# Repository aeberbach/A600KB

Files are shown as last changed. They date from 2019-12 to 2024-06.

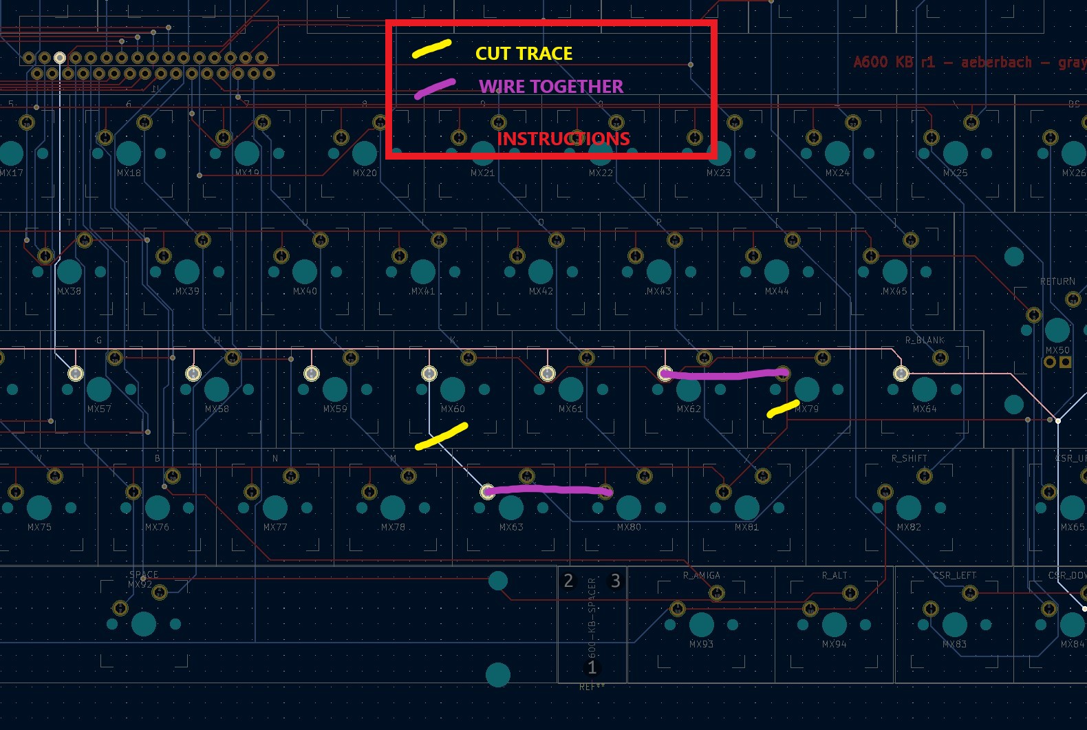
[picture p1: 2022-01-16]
A600-kb-fix.jpg

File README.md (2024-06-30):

# A600KB: Mechanical keyboard Amiga A600

Like my A1200 project (see my other repos) this is a mechanical keyboard for an Amiga computer.

To make one you need:
- PCBs, which you can make by sending the contents of the 'fab' folder to your local PCB maker.
- 3D printed parts: the STL files are in the STL folder. I used a Prusa MK3S 0.25mm nozzle, Urban Grey PETG.
- 78 MX PCB-mount switches
- 32-way FFC connector (Mouser part number 538-52044-3245)
- 32-way ribbon cable (Mouser part number 538-15168-0400)
- keyswitch stabiliser for Tab and Enter keys
- one 3mm LED for CapsLock
- keycaps

For more details about design choices and putting it together please see the article on grayunicorn.com. 

Enjoy!

May 2022 Update - this is now release 2. Apart from correcting swapped keys that existed in revision 1 (see below) I made a lot of traces simpler. I used KiCAD 6 for this, it just keeps getting better. If you build a revision 2 I would love to hear about it.

Revision 1 Errata:
Many people have built it and never noticed. That goes for me too - one person contacted me and said they were having trouble with some music tracker software because it relies on the keys that are not in the right place. I had not noticed because I had not been using software that relied on those
keys - sorry if you were affected! The revision 1 PCB should be modified:

- Line 5: disconnect from MX63 (< ,) column; connect to MX79 (" ') column
- Line 7: disconnect from MX79 (" ') column; connect to MX63 (< ,) column
- Line 23: disconnect from MX79 (" ') row; connect to MX63 (< ,) row
- Line 26: disconnect from MX63 (< ,) row; connect to MX79 (" ') row

The PCB has been revised to revision 2 (the same as Commodore's schematic) now so this is fixed, but if you have a revision 1 and notice the ' and , appear to be swapped then you may need to apply this change.

Note this this project is licensed under CC BY-NC-SA 4.0 - only noncommercial use is permitted! (By all means sell the excess PCBs you get, at cost, if you order some for your own use)

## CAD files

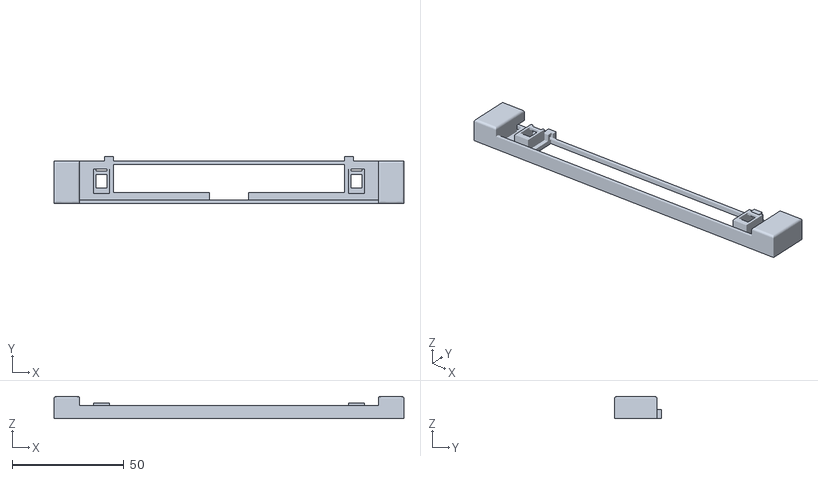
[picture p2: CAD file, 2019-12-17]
STL/A600-7U-Spacebar-Assembly.stl
156.5 x 21.0 x 10.0

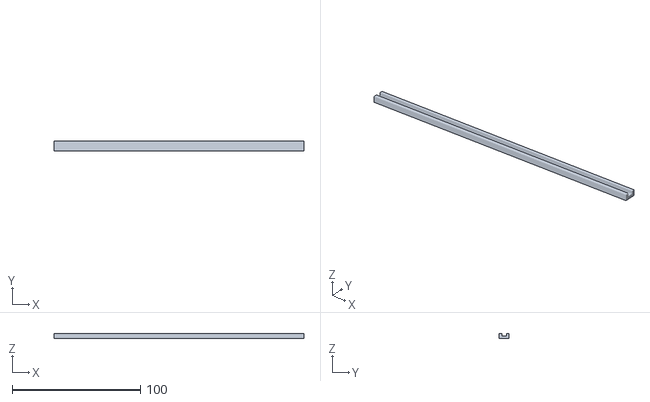
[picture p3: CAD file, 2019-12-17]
STL/Rail.stl
195.0 x 8.00 x 4.00

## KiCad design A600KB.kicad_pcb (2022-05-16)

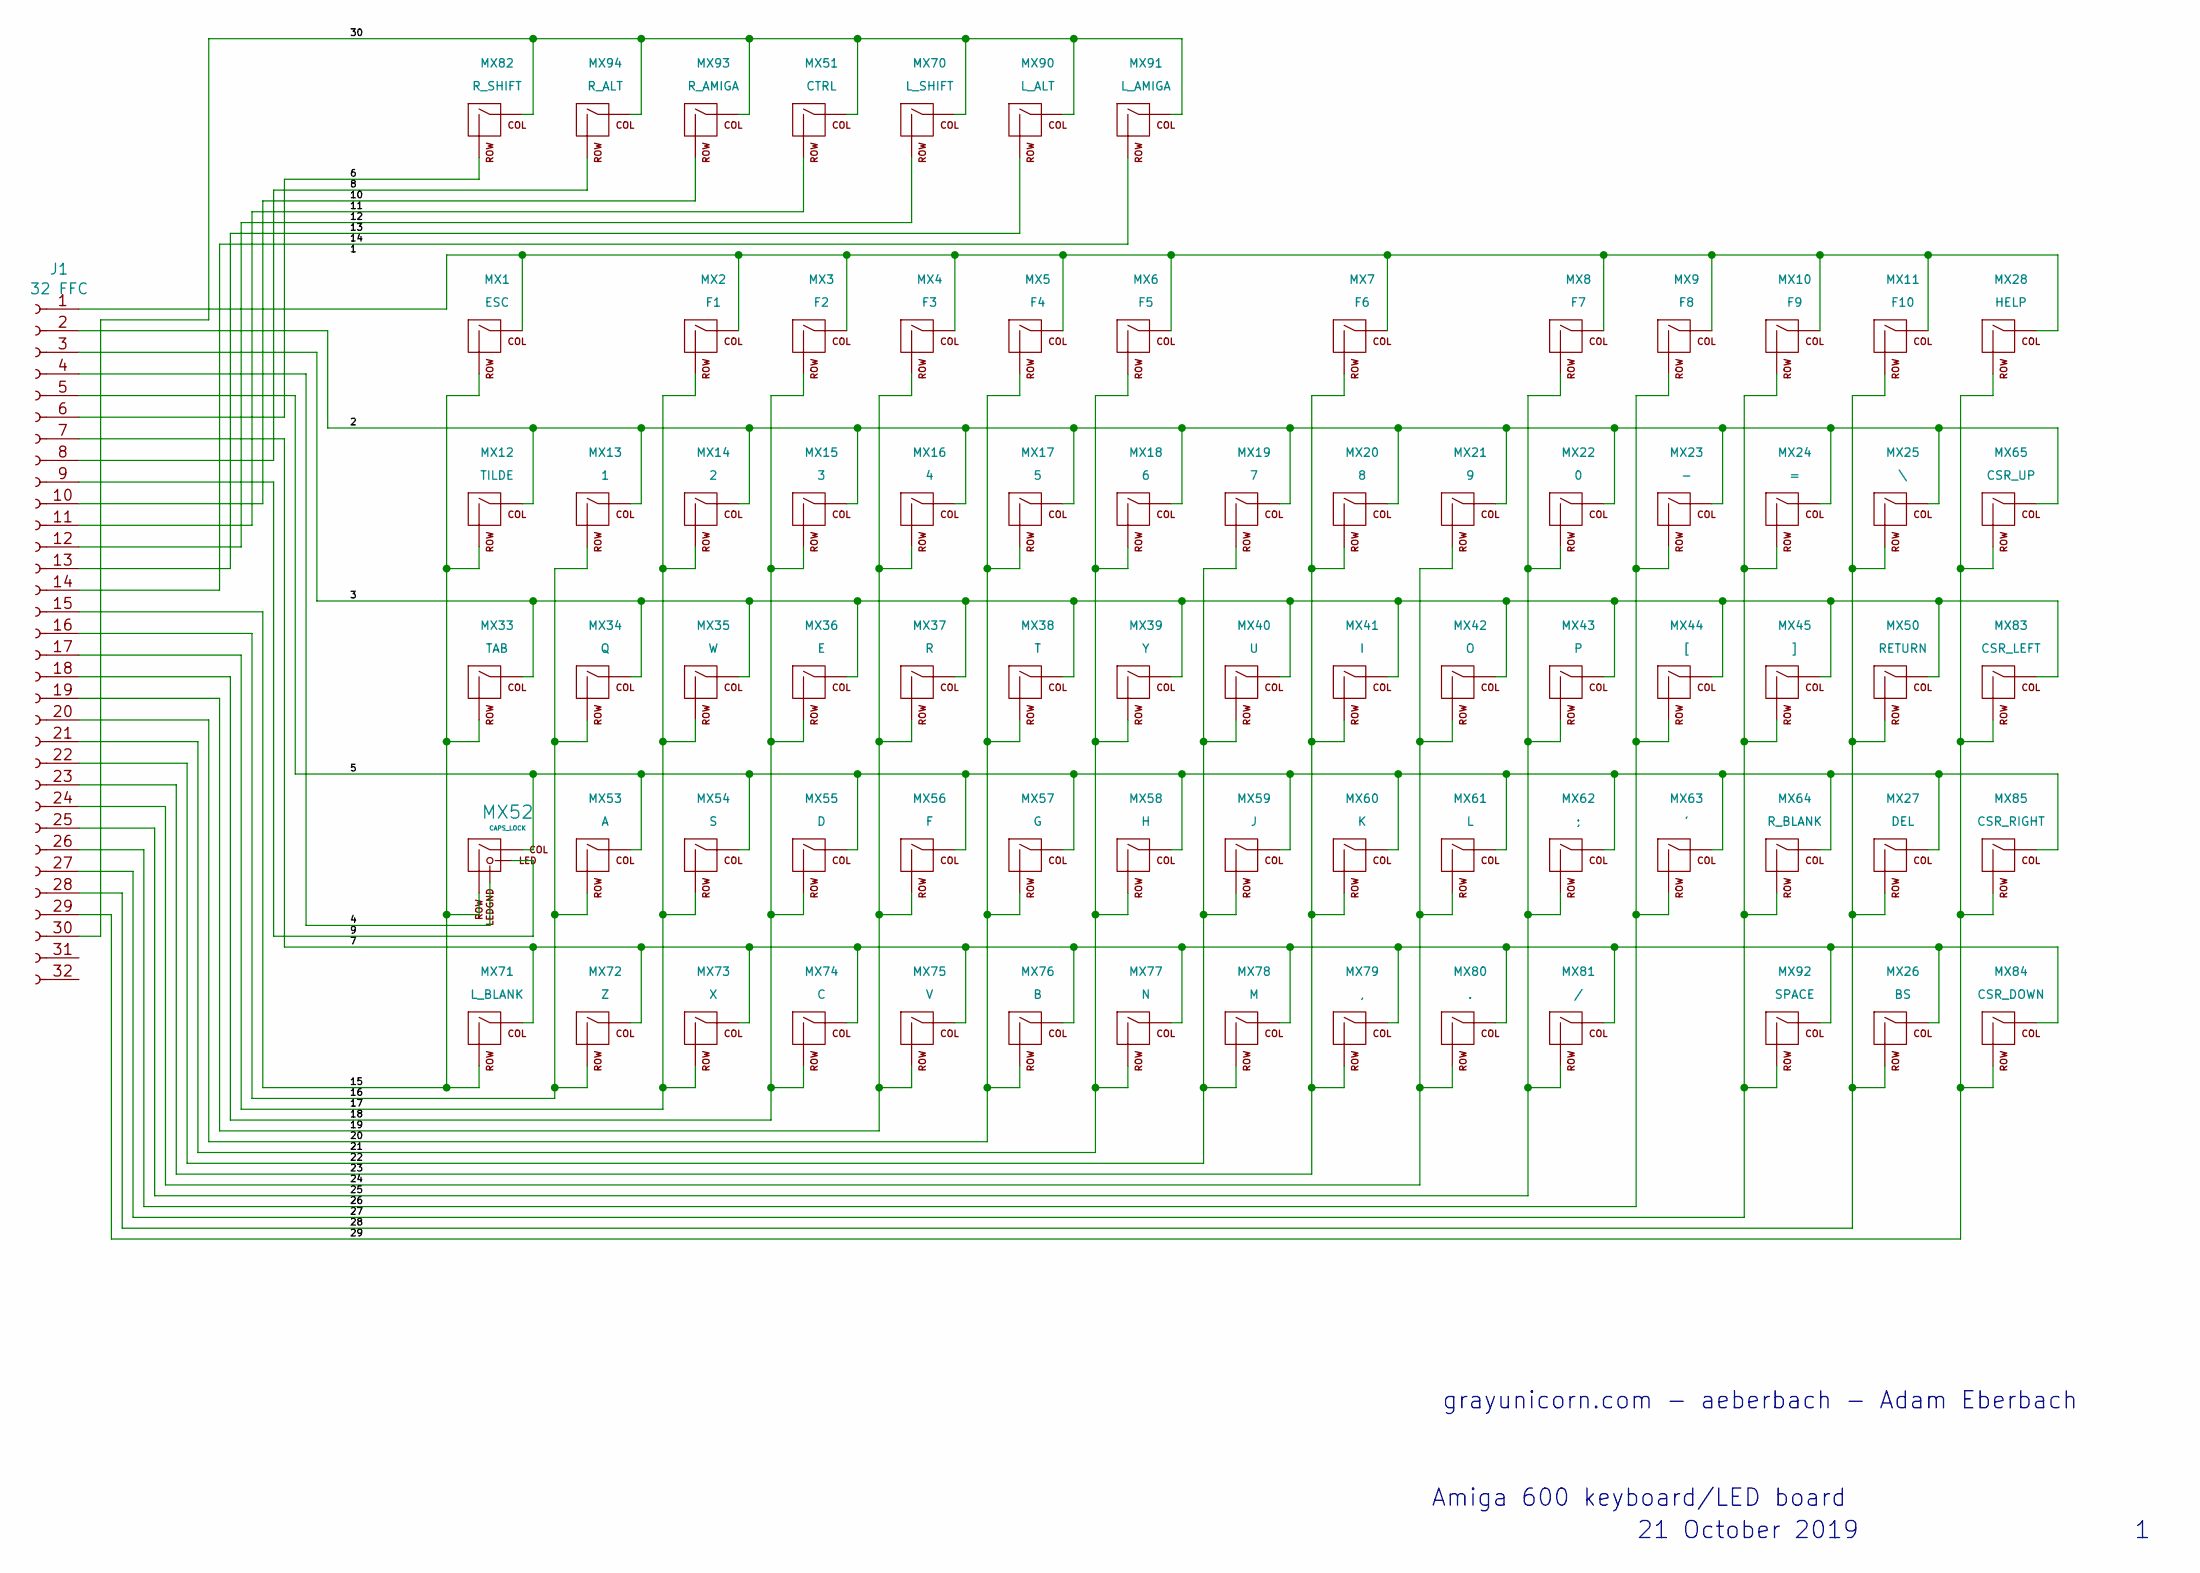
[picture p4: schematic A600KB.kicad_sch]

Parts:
J1: 32 FFC; FFC-1.25mm-RA-5204403245
MX1: ESC; MXOnly-1.25U-NoLED
MX2: F1; MXOnly-1.25U-NoLED
MX3: F2; MXOnly-1.25U-NoLED
MX4: F3; MXOnly-1.25U-NoLED
MX5: F4; MXOnly-1.25U-NoLED
MX6: F5; MXOnly-1.25U-NoLED
MX7: F6; MXOnly-1.25U-NoLED
MX8: F7; MXOnly-1.25U-NoLED
MX9: F8; MXOnly-1.25U-NoLED
MX10: F9; MXOnly-1.25U-NoLED
MX11: F10; MXOnly-1.25U-NoLED
MX12: TILDE; MXOnly-1.5U-NoLED
MX13: 1; MXOnly-1U-NoLED
MX14: 2; MXOnly-1U-NoLED
MX15: 3; MXOnly-1U-NoLED
MX16: 4; MXOnly-1U-NoLED
MX17: 5; MXOnly-1U-NoLED
MX18: 6; MXOnly-1U-NoLED
MX19: 7; MXOnly-1U-NoLED
MX20: 8; MXOnly-1U-NoLED
MX21: 9; MXOnly-1U-NoLED
MX22: 0; MXOnly-1U-NoLED
MX23: -; MXOnly-1U-NoLED
MX24: =; MXOnly-1U-NoLED
MX25: \; MXOnly-1U-NoLED
MX26: BS; MXOnly-1U-NoLED
MX27: DEL; MXOnly-1U-NoLED
MX28: HELP; MXOnly-1.25U-NoLED
MX33: TAB; MXOnly-2U-NoLED
MX34: Q; MXOnly-1U-NoLED
MX35: W; MXOnly-1U-NoLED
MX36: E; MXOnly-1U-NoLED
MX37: R; MXOnly-1U-NoLED
MX38: T; MXOnly-1U-NoLED
MX39: Y; MXOnly-1U-NoLED
MX40: U; MXOnly-1U-NoLED
MX41: I; MXOnly-1U-NoLED
MX42: O; MXOnly-1U-NoLED
MX43: P; MXOnly-1U-NoLED
MX44: [; MXOnly-1U-NoLED
MX45: ]; MXOnly-1U-NoLED
MX50: RETURN; MXOnly-ISO
MX51: CTRL; MXOnly-1.25U-NoLED
MX52: CAPS_LOCK; MXOnly-1U
MX53: A; MXOnly-1U-NoLED
MX54: S; MXOnly-1U-NoLED
MX55: D; MXOnly-1U-NoLED
MX56: F; MXOnly-1U-NoLED
MX57: G; MXOnly-1U-NoLED
MX58: H; MXOnly-1U-NoLED
MX59: J; MXOnly-1U-NoLED
MX60: K; MXOnly-1U-NoLED
MX61: L; MXOnly-1U-NoLED
MX62: ;; MXOnly-1U-NoLED
MX63: '; MXOnly-1U-NoLED
MX64: R_BLANK; MXOnly-1U-NoLED
MX65: CSR_UP; MXOnly-1U-NoLED
MX70: L_SHIFT; MXOnly-1.75U-NoLED
MX71: L_BLANK; MXOnly-1U-NoLED
MX72: Z; MXOnly-1U-NoLED
MX73: X; MXOnly-1U-NoLED
MX74: C; MXOnly-1U-NoLED
MX75: V; MXOnly-1U-NoLED
MX76: B; MXOnly-1U-NoLED
MX77: N; MXOnly-1U-NoLED
MX78: M; MXOnly-1U-NoLED
MX79: ,; MXOnly-1U-NoLED
MX80: .; MXOnly-1U-NoLED
MX81: /; MXOnly-1U-NoLED
MX82: R_SHIFT; MXOnly-1.75U-NoLED
MX83: CSR_LEFT; MXOnly-1U-NoLED
MX84: CSR_DOWN; MXOnly-1U-NoLED
MX85: CSR_RIGHT; MXOnly-1U-NoLED
MX90: L_ALT; MXOnly-1.25U-NoLED
MX91: L_AMIGA; MXOnly-1.25U-NoLED
MX92: SPACE; MXOnly-7U
MX93: R_AMIGA; MXOnly-1.25U-NoLED
MX94: R_ALT; MXOnly-1U-NoLED

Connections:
/2: J1.2, MX12.1 (COL), MX13.1 (COL), MX14.1 (COL), MX15.1 (COL), MX16.1 (COL), MX17.1 (COL), MX18.1 (COL), MX19.1 (COL), MX20.1 (COL), MX21.1 (COL), MX22.1 (COL), MX23.1 (COL), MX24.1 (COL), MX25.1 (COL), MX65.1 (COL)
/3: J1.3, MX33.1 (COL), MX34.1 (COL), MX35.1 (COL), MX36.1 (COL), MX37.1 (COL), MX38.1 (COL), MX39.1 (COL), MX40.1 (COL), MX41.1 (COL), MX42.1 (COL), MX43.1 (COL), MX44.1 (COL), MX45.1 (COL), MX50.1 (COL), MX83.1 (COL)
/4: J1.4, MX52.4 (LEDGND)
/5: J1.5, MX27.1 (COL), MX52.1 (COL), MX53.1 (COL), MX54.1 (COL), MX55.1 (COL), MX56.1 (COL), MX57.1 (COL), MX58.1 (COL), MX59.1 (COL), MX60.1 (COL), MX61.1 (COL), MX62.1 (COL), MX63.1 (COL), MX64.1 (COL), MX85.1 (COL)
/6: J1.6, MX82.2 (ROW)
/7: J1.7, MX26.1 (COL), MX71.1 (COL), MX72.1 (COL), MX73.1 (COL), MX74.1 (COL), MX75.1 (COL), MX76.1 (COL), MX77.1 (COL), MX78.1 (COL), MX79.1 (COL), MX80.1 (COL), MX81.1 (COL), MX84.1 (COL), MX92.1 (COL)
/8: J1.8, MX94.2 (ROW)
/9: J1.9, MX52.3 (LED)
/10: J1.10, MX93.2 (ROW)
/11: J1.11, MX51.2 (ROW)
/12: J1.12, MX70.2 (ROW)
/13: J1.13, MX90.2 (ROW)
/14: J1.14, MX91.2 (ROW)
/15: J1.15, MX1.2 (ROW), MX12.2 (ROW), MX33.2 (ROW), MX52.2 (ROW), MX71.2 (ROW)
/16: J1.16, MX13.2 (ROW), MX34.2 (ROW), MX53.2 (ROW), MX72.2 (ROW)
/17: J1.17, MX2.2 (ROW), MX14.2 (ROW), MX35.2 (ROW), MX54.2 (ROW), MX73.2 (ROW)
/18: J1.18, MX3.2 (ROW), MX15.2 (ROW), MX36.2 (ROW), MX55.2 (ROW), MX74.2 (ROW)
/19: J1.19, MX4.2 (ROW), MX16.2 (ROW), MX37.2 (ROW), MX56.2 (ROW), MX75.2 (ROW)
/20: J1.20, MX5.2 (ROW), MX17.2 (ROW), MX38.2 (ROW), MX57.2 (ROW), MX76.2 (ROW)
/21: J1.21, MX6.2 (ROW), MX18.2 (ROW), MX39.2 (ROW), MX58.2 (ROW), MX77.2 (ROW)
/22: J1.22, MX19.2 (ROW), MX40.2 (ROW), MX59.2 (ROW), MX78.2 (ROW)
/23: J1.23, MX7.2 (ROW), MX20.2 (ROW), MX41.2 (ROW), MX60.2 (ROW), MX79.2 (ROW)
/24: J1.24, MX21.2 (ROW), MX42.2 (ROW), MX61.2 (ROW), MX80.2 (ROW)
/25: J1.25, MX8.2 (ROW), MX22.2 (ROW), MX43.2 (ROW), MX62.2 (ROW), MX81.2 (ROW)
/26: J1.26, MX9.2 (ROW), MX23.2 (ROW), MX44.2 (ROW), MX63.2 (ROW)
/27: J1.27, MX10.2 (ROW), MX24.2 (ROW), MX45.2 (ROW), MX64.2 (ROW), MX92.2 (ROW)
/28: J1.28, MX11.2 (ROW), MX25.2 (ROW), MX26.2 (ROW), MX27.2 (ROW), MX50.2 (ROW)
/29: J1.29, MX28.2 (ROW), MX65.2 (ROW), MX83.2 (ROW), MX84.2 (ROW), MX85.2 (ROW)
/30: J1.30, MX51.1 (COL), MX70.1 (COL), MX82.1 (COL), MX90.1 (COL), MX91.1 (COL), MX93.1 (COL), MX94.1 (COL)
unnamed: J1.1, MX1.1 (COL), MX2.1 (COL), MX3.1 (COL), MX4.1 (COL), MX5.1 (COL), MX6.1 (COL), MX7.1 (COL), MX8.1 (COL), MX9.1 (COL), MX10.1 (COL), MX11.1 (COL), MX28.1 (COL)

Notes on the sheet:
21 October 2019
grayunicorn.com - aeberbach - Adam Eberbach
Amiga 600 keyboard/LED board

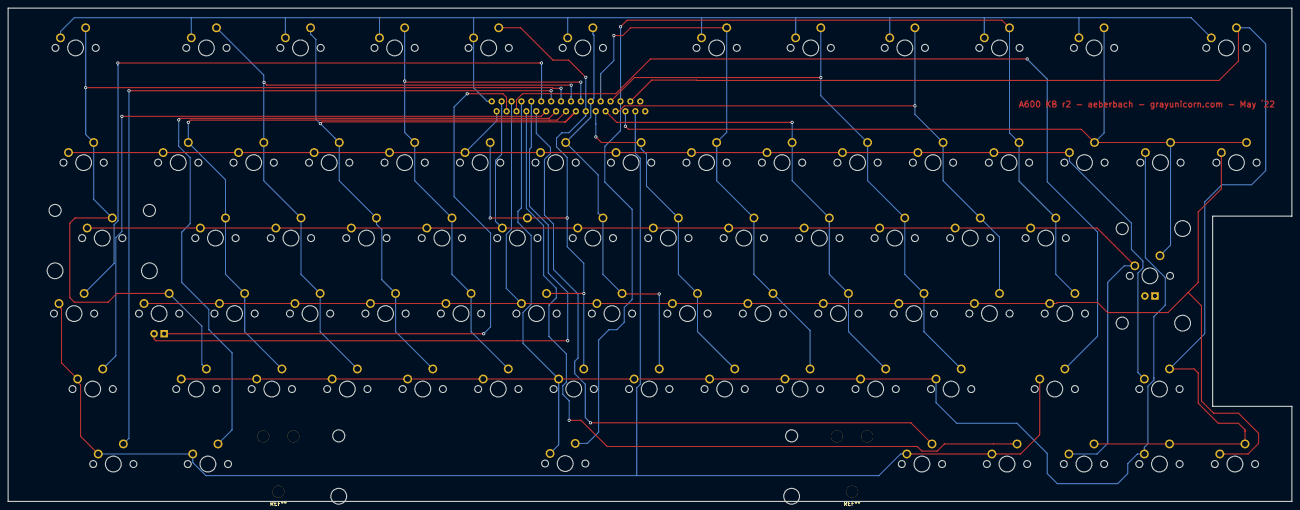
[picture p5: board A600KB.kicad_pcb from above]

Board: 2 copper layers, 324.0 x 124.5 mm, 79 parts (1 on the bottom side), 30 nets.

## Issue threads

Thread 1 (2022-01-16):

Incorrect wiring rev 1

aeberbach, 2022-01-16:
Apply fix as per root folder jpg to PCB/schematic files and update to correct rev 1 bug where keys MX63 and MX79 are swapped

Closed 2023-11-09.

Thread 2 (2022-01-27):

Missing donate button

OleUrgast, 2022-01-27:
Hello,
thanks for your great PCB-designs.

In your readme.md of the A600 keyboard PCB you forget to add the "Donate" buton at the end.

As there is one at the end of the A1200 keyboard PCB description, I used that, but you might add one at A600 description as well ;-)

Also you might upload your projects to PCBWAY as a shared project and set a link to it in your description. This has two advantages:

1. It makes it more easy for everyone to order PCBs, as many people never uploaded a gerber before.
2. If someone orders your PCBs, you get 10% of the price as credit points. You can use theese to pay for PCBs you order yourself. So future developments might cost less.

Maybe other companys have simular reward systems. While you get rewarded, the customer has no extra cost. Win-Win situation.

As communication by paypal is limited (paypal showed an error message), here the answer to your question:

I got 10 PCBs of the A600 mechanical keyboard PCB. As the minimum order quantity on PCBWAY is 5 (about 90€ incl. Tax and shipping) and 10 are only 30€ more, I ordered 10.
Maybe someone else in germany might need one, and if I have spare ones after I did my own projects, I migth give them away at a self-cost basis.

My goal is to build an Amiga Emulator close as possible to the original without harming any original Amiga. So self printed case is a must. As the biggest printer with textured spring steel I have at the moment is an Anycubic Chiron (but I need to repair it first), I am limited to A600. This is the best choice for an emulator anyway in my opinion - while bigger than a Pi400 its much more portable than an A500 or A1200 (or an A4000T ;-). But it has still enough space inside to integrate a DrawBridge with floppy drive and a slot-in CD-Drive.

Also [Thinghacker](https://github.com/thinghacker/Amiga600KeyboardUSBAdapter) already designed an A600 keyboard to USB adapter based on a Raspberry Pico, so your PCB is quite easy to use with emulators.

Also an Amiga has a quite simular keyboard as a PC. I intend to place the 3 LEDs to switches to add hidden keys for F11, F12(esp. important to call emulator settings) and an FN-Key. So the "Amiga emulator" can also be used as an Office PC with Raspbian simply by swapping SD-Cards. With more powerful Pi's every few years and my slow progress on projects, in the final version it might be the Pi 5 or Pi 6 I fear ;-)

I just wait for some parts from China (brown keys, 30pin FCC 1.25 pitch connectors and cables, some chips for the controller etc., Thinghackers’s PCB) to start the project.

For keycaps I want to use the keycap generator from thingiverse and a resin printer. So blank keycaps in original size and profile should not be a problem at all (also spacebar in any lengh you want can be generated. ISO-Enter is faulty, but there are other designs available on thingiverse to print an ISO-enter).

Labeling keycaps is a bit more complicated. While the keycap generator can "engrave" labels directly into the design, this would not look like an original Amiga keyboard. Of course you could carefully fill the engravement with a fine brush with black resin, to make a "double shot" keycap and than wetsanding and polish the top of the cap to make the key perfect, but that seems to be a lot of work to do.

But I found other methods to label keycaps in the web:

- DyeSub method: (there are some nice videos on youtube how to DyeSub on keycaps). Of course you can only dysub darker than the keycap, so no white on black printing this way (this is quite sad, as I want to print one A600 case with black carbon fibre enforced filament). A problem might be standard resin glas transition temperature being significant lower than ABS (and even ABS can be deformed doing a DyeSub). I will definitly try it. HighTemp (glas transition temperature 220°C) resins are colour limited (I only found gray) but availabe for a reasonable price (Phrozen TR300 ultra-high-temp resin gray, 85€/l). I also found a more interesting resin in white: Formfutura High Performance Series Rigid Ceramic Resin white, a ceramic-like resin with "high tempeature resistance" (whatever this means), which should survive the 75 seconds of DyeSubing. Only available in white and not cheap (125€/0.75l), but 0.75 liter should be enough for more than 10 keysets. But I do not think I will have time to try that this year (but I am very courious how the feel of a ceramic-like resin is).

To DyeSub you need a special ink in a piezo Inkjet printer. I actually have an old Ricoh Afficio which works well (but as I needed a bigger printer I barely used it). Anyway, as it was out of ink and leaving an Inkjet with permanent printhead out of ink for a longer time will damage the printhead, I decided to buy DyeSub ink for this printer. Only made two Amiga mousepads at the moment, but that worked well.

As dyesub transfer is used in most print-shops to print individual pictures on t-shirts, cups, mousepads etc. you actually do not need such a printer yourself. Just ask a printshop to print your "picture" (with all the labels you need) with DyeSub ink on DyeSub paper (mirrored of course). Should not cost much.

- Embossing powder. You make a stamp with the label for you keycap (using photopolymere rubber stamp material), stamp glycol onto the keycap, put ultra fine embossing powder onto the keycap, turn the keycap, so all powder exept there the glycol is, falls down. Than use a heatgun to melt the powder. While this also uses heat, there is no preasure involved. So a good chance the keycap survives this 60 second treatment. This should work also white on black (CDTV or own colour sheme). But I do not know how wear resistant the print is.

- two part design: cut keycap model in two parts. Upper 2mm print in high transparent resin. The other part whatever resin you like. Print labels with a laserprinter on foil. Than glue bottom part, foil and top part together using epoxy to embed the print inside the keycap (avoid bubbles). You might have to post-process the sides of the keycap (put some grease to the sides of the keycap before glueing parts together to make it easy to remove any epox coming out at the sides while pressing parts together).

- printer for printing on plastic: These are available for doing merchandise articles (logos on pens, lightner etc.). Some small companys also use them to print on Lego bricks (Lego use some shabby stickers even on some UCS-models). Starting at about €2000 ($-AD 3000) it might be possible to buy one for privat use. But having other hobbys also it is much surely out of budget for most people. Also I know nothing about the wear resistance of the prints.

While I researced a lot about making and printing keycaps (or in general: Print on plastic), exept for embossing powder and making stamps I have not tried out the other methods yet. Still waiting for some parts from china...

One question: Is there a special reason your A600 Keyboard PCB using 32pin FCC 1.25mm instead 30pin? The 30pin connectors and cables seem easyly available on AliExpress, while 32pin I only found  at Mouser. As Mouser is not represented in Germany, minimum value of the order or shipping cost are quite high...
As I want to use the Keyboard inside an emulator, I do not know if it even matters - I have to check correct orientation and wireing, but maybe I can simply directly sandwich Thinghacker's controller to the keyboard PCB using two rows of pins and spare the efford for theese special cables and connectors completly.

aeberbach, 2023-11-09:
OleUrgast I am so sorry I missed this comment - notification from GitHub really needs to be better!

I think you could use the 30-circuit connector, sure. I specified Mouser because it's the one I use, and I did not think to check AliExpress. In fact I assumed the FFC connectors and sockets in that pitch were thoroughly obsolete and it was only the larger distributors that might have new old stock remaining. At least if the Mouser part number is given then a specific part is identified and any substitute is up to the individual maker.

Great info on the keycaps. I now have kept one Amiga, the A1200 and in it is a ReAmiga 1.5. Even the LED assembly was built by me! I am using one full set of keycaps from Signature Plastics, which I had to order as a set and then around 30 individual special order keys, but I did get the full set of Amiga keycaps in the right sizes. The cost was unfortunate...

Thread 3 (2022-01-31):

Caps lock switch and LED wrong direction

OleUrgast, 2022-01-31:
Hello,
the original A600 keycap has the LED window at the top right, not at the bottom. So capslock switch has to be rotated and LED placed at the top.
Maybe you can design this part to mount the switch and LED in both directions, as there are indeed old Cherry keycaps with window at the bottom of the keycap (the original A2000(A) Rev. 4.x Braunschweig Edition keyboard has such a keycap)

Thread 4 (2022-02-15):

Plate for Plate mounted switches

OleUrgast, 2022-02-15:
Hello,
as I have a lot of 3-pin switches and align them on a PCB, I designed a plate for plate-mounting.
Actually I sourced blue keys from a cheap Aukey keyboard from Aliexpress, where one key was defect. Also got he stabalizers that way (cherry-style plate mounted).
As I do not have an original A600, I do not know about mounting. Still it might be usefull, as it not only helps to align the keys, but also add a lot of stiffness (even if you cut it to print it in two parts).
I created most of the keys with a keycap generator. Space is 8.25u and stabilzer points are same as on 6.25u spacebars - so both spacebars work. I am still optimizing the keycaps (ISO enter in OEM-Profile seems hard to design) and will publish the set as soon it is ready.
Maybe the plate is usefull for others, so I attatch the final beta
[A600.42.final beta.stl.zip](https://github.com/aeberbach/A600KB/files/8075396/A600.42.final.beta.stl.zip)
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
.

steveed, 2024-05-01:
@OleUrgast Are you still working on this plate? I works great but there are a few issues when installing it in the A600. It's a bit thick in places so it makes it bow a little.  The other issue is that the full size space bars have the stabilizers at 8u. I think that is the measurement, same as the a1200 pcb. It prints great and makes the keyboard feel a lot better, just need to figure out the spacebar. I can deal with the slight bow.

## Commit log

2019-10-21 Schematic without connectors
    [A600KB.sch]
2019-10-21 footprints for connectors
    [A600KB.sch]
2019-10-21 correct annotations
    [A600KB.sch]
2019-11-19 Finished, sent to fab
    PCB Order
    Weight:
    1kg
    Project Name:
    A600 r1
    Length:
    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
    [A600KB-B_Cu.gbr, A600KB-B_Mask.gbr, A600KB-Edge_Cuts.gbr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]
2019-12-17 STIL files for 3D-printed parts
    [A600-7U-Spacebar-Assembly.stl, Rail.stl]
2022-04-13 README fix instructions; new Kicad version update
2022-04-13 update kicad version
    [A600KB.kicad_pcb, A600KB.kicad_sch]
2022-05-16 Revise PCB to fix swapped keys
    [A600KB-B_Cu.gbr, A600KB-B_Mask.gbr, A600KB-Edge_Cuts.gbr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]
2024-06-30 OPened with KiCAD 8
